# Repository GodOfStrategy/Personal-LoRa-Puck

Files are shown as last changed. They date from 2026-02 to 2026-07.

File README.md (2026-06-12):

# Personal-LoRa-Module
A small compact module made to transmit and receive messages using sub gigahertzs frequencies of radio waves, for use in things such as automation, transmission, reception etc. I wanted to build this for a long time, because I want to implement noise pollution control using these modules, where one module will monitor honking >3 seconds and relay the information of the defaulter's vehicle to the receiver and fine the defaulter.

My LoRa module uses Sub GHz frequencies to tranceive radio waves. It uses the following components:
1. SX1262IMLTRT for transmission and reception.
2. RP2040 for Programing it for various applications.
3. 0900FM15D0039E as an RF filter.
4. AP2112K-3.3 as my LDO.
5. PE4259 as my RF switch.
6. Two quartz timer crystals (12 MHz and 32 MHz).
7. SMD Resistors.
8. SMD Capacitors.
9. SMD Inductors.
10. USB-C Receptacle.

Here is the Schematic:


Here is the PCB:


Here is the assembled PCB:


[Lora-BOM-2.csv](https://github.com/user-attachments/files/28879576/Lora-BOM-2.csv)
Please find the BOM and Firmware along with a 3D STEP file for my assembled PCB in my repo.

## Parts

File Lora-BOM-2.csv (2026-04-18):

Reference | Qty | Value | DNP | Exclude from BOM | Price ($) | Footprint | Datasheet
AE1 | 1 | Antenna |  |  | 4.53 | Connector_PinSocket_2.54mm:PinSocket_1x01_P2.54mm_Vertical | ~
C1,C2 | 2 | 100 nf |  |  | 0.091 | Capacitor_SMD:C_0402_1005Metric | ~
C3 | 1 | 47 nF |  |  | 0.114 | Capacitor_SMD:C_0402_1005Metric | ~
C4,C5 | 2 | 47 pF |  |  | 0.024 | Capacitor_SMD:C_0402_1005Metric | ~
C6 | 1 | 1 nF |  |  | 0.024 | Capacitor_SMD:C_0402_1005Metric | ~
C7,C21 | 2 | 1 uF |  |  | 0.044 | Capacitor_SMD:C_0402_1005Metric | ~
C8,C9,C11,C12,C13,C14,C15,C22,C23 | 9 | 100 nF |  |  | 0.091 | Capacitor_SMD:C_0402_1005Metric | ~
C10,C24 | 1 | 100 nF (C8 - C14 &C24) |  |  | 0.024 | Capacitor_SMD:C_0402_1005Metric | ~
C16,C17 | 2 | 10 uF |  |  | 0.2508 | Capacitor_SMD:C_0402_1005Metric | ~
C18 | 1 | 39 pF |  |  | 0.024 | Capacitor_SMD:C_0402_1005Metric | ~
C19,C20 | 2 | 3.3 pF |  |  | 0.324 | Capacitor_SMD:C_0402_1005Metric | ~
FB1 | 1 | BLM15AX102SN1D |  |  | 0.118 | Inductor_SMD:L_0402_1005Metric | ~
J1 | 1 | USB_C_Receptacle_USB2.0_16P |  |  | 5.088 | Connector_USB:USB_C_Receptacle_G-Switch_GT-USB-7010ASV | https://www.usb.org/sites/default/files/documents/usb_type-c.zip
L1 | 1 | 15uH |  |  | 0.136 | Inductor_SMD:L_0402_1005Metric | ~
L2 | 1 | 47 nH |  |  | 0.1737 | Inductor_SMD:L_0402_1005Metric | ~
L3 | 1 | 9.1 nH |  |  | 0.074 | Inductor_SMD:L_0402_1005Metric | ~
R1 | 1 | 100 |  |  | 0.012 | Resistor_SMD:R_0402_1005Metric | ~
R2,R3 | 2 | 27.4 |  |  | 0.064 | Resistor_SMD:R_0402_1005Metric | ~
R4 | 1 | 10k |  |  | 0.012 | Resistor_SMD:R_0402_1005Metric | ~
R5 | 1 | 1k |  |  | 0.012 | Resistor_SMD:R_0402_1005Metric | ~
R6,R7 | 2 | 5.1 k |  |  | 0.008 | Resistor_SMD:R_0402_1005Metric | ~
SW2 | 1 | BOOTSEL |  |  | 3.39 | Button_Switch_SMD:SW_SPST_PTS647_Sx70 | ~
SW3 | 1 | RESET |  |  |  | Button_Switch_SMD:SW_SPST_PTS647_Sx70 | ~
U1 | 1 | SX1262IMLTRT |  |  | 16.4875 | Package_DFN_QFN:QFN-24-1EP_4x4mm_P0.5mm_EP2.6x2.6mm | https://semtech.file.force.com/sfc/dist/version/download/?oid=00DE0000000JelG&ids=0682R00000IjPWSQA3
U2 | 1 | RP2040 |  |  | 4.827 | Package_DFN_QFN:QFN-56-1EP_7x7mm_P0.4mm_EP3.2x3.2mm | https://datasheets.raspberrypi.com/rp2040/rp2040-datasheet.pdf
U3 | 1 | PE4259 |  |  | 3.0815 | Package_TO_SOT_SMD:SOT-363_SC-70-6 | https://lcsc.com/datasheet/lcsc_datasheet_2409301504_pSemi-PE4259-63_C470892.pdf
U4 | 1 | 0900FM15D0039E |  |  | 9.62` | RF_Converter:Balun_Johanson_0900FM15K0039 | 0900FM15D0039E
U5 | 1 | 12 MHz |  |  | 1.231 | Package_SO:SOIC-8_5.3x5.3mm_P1.27mm | https://www.winbond.com/resource-files/w25q128jv_dtr%20revc%2003272018%20plus.pdf
U6 | 1 | AP2112K-3.3 |  |  | 0.6714 | Package_TO_SOT_SMD:SOT-23-5 | https://www.diodes.com/assets/Datasheets/AP2112.pdf
Y1 | 1 | 32MHz |  |  | 1.405 | Crystal:Crystal_SMD_3225-4Pin_3.2x2.5mm | ~

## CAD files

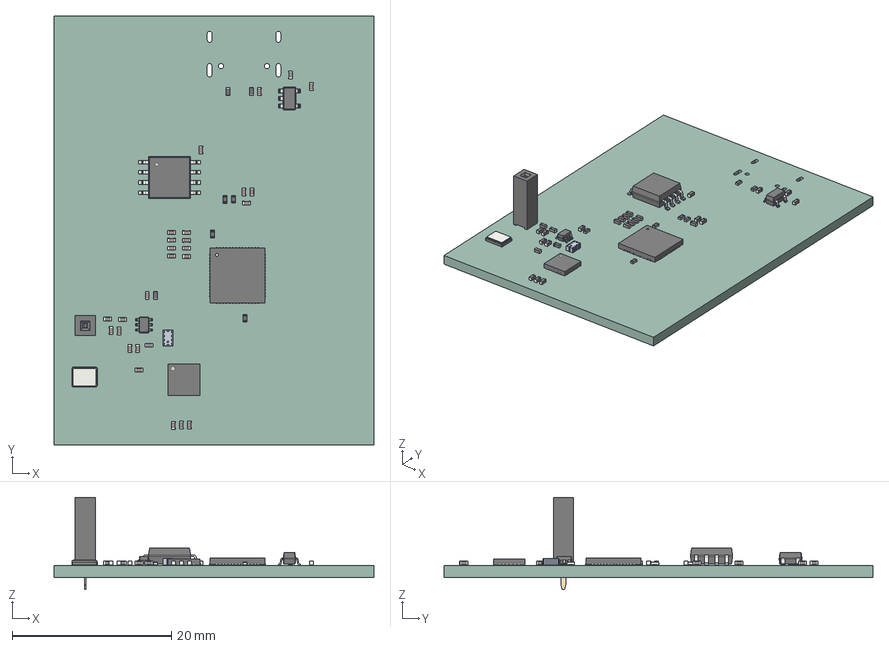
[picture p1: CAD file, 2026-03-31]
lora.step
40.2 x 53.9 x 11.6 mm
C_0402_1005Metric x 23
R_0402_1005Metric x 7
PinSocket_1x01_P2.54mm_Vertical
SOIC-8_5.3x5.3mm_P1.27mm
QFN-24-1EP_4x4mm_P0.5mm_EP2.6x2.6mm
L_0402_1005Metric x 4
SOT-23-5
SOT-363_SC-70-6
QFN-56-1EP_7x7mm_P0.4mm_EP3.2x3.2mm
lora 1.39.1
lora 1.39.2
lora 1.39.3
Crystal_SMD_3225-4Pin_3.2x2.5mm
lora_PCB

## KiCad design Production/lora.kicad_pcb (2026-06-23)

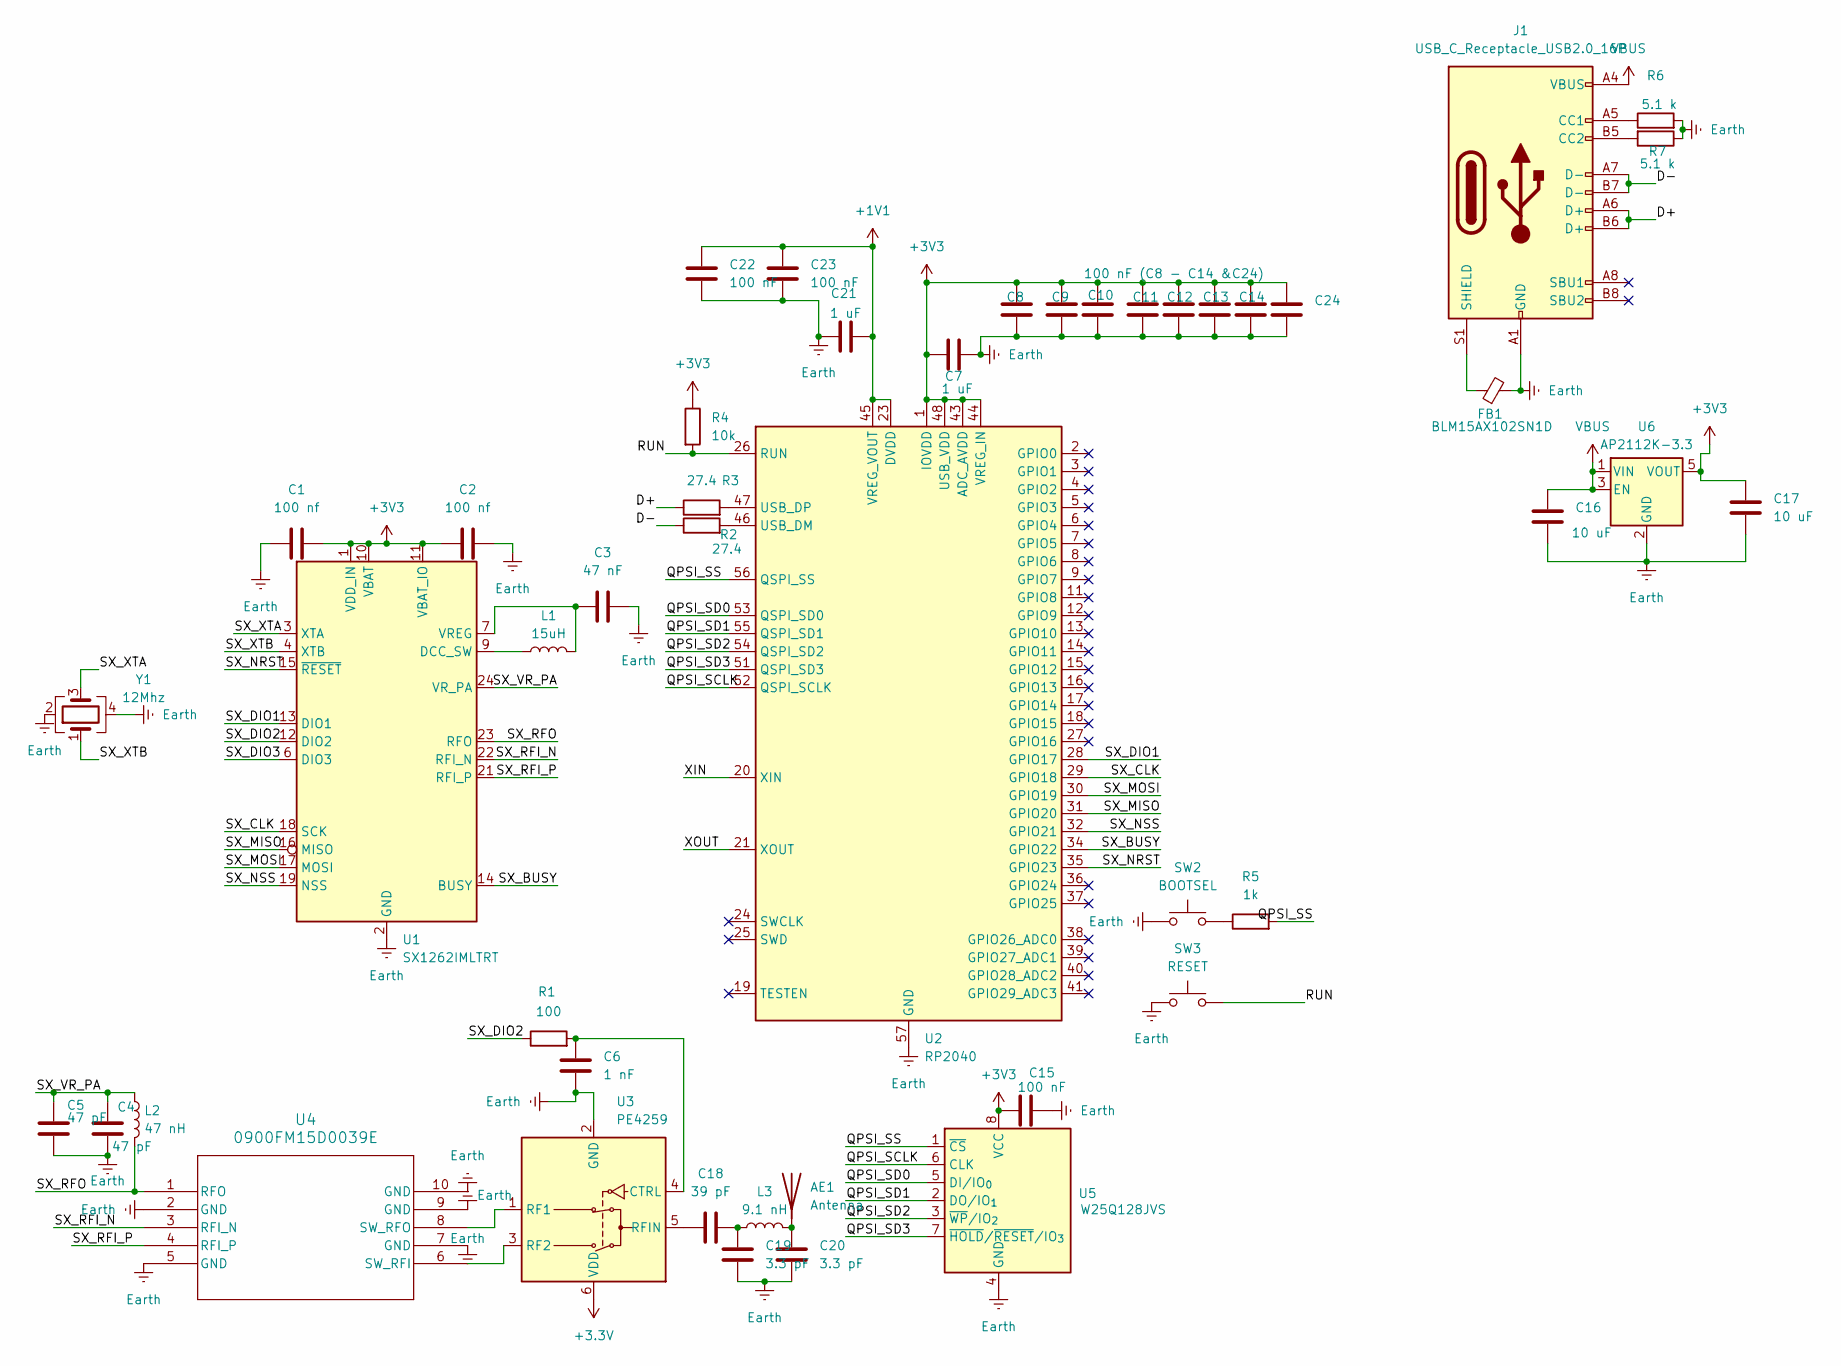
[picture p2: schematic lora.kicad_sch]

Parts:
AE1: Antenna; PinSocket_1x01_P2.54mm_Vertical
C1, C2: 100 nf; C_0402_1005Metric
C3: 47 nF; C_0402_1005Metric
C4, C5: 47 pF; C_0402_1005Metric
C6: 1 nF; C_0402_1005Metric
C7, C21: 1 uF; C_0402_1005Metric
C8, C9, C11, C12, C13, C14, C15, C22, C23: 100 nF; C_0402_1005Metric
C10: 100 nF (C8 - C14 &C24); C_0402_1005Metric
C16, C17: 10 uF; C_0402_1005Metric
C18: 39 pF; C_0402_1005Metric
C19, C20: 3.3 pF; C_0402_1005Metric
C24: 100nF; C_0402_1005Metric
FB1: BLM15AX102SN1D; L_0402_1005Metric
J1: USB_C_Receptacle_USB2.0_16P; USB_C_Receptacle_G-Switch_GT-USB-7010ASV
L1: 15uH; L_0201_0603Metric
L2: 47 nH; L_0402_1005Metric
L3: 9.1 nH; L_0402_1005Metric
R1: 100; R_0402_1005Metric
R2, R3: 27.4; R_0402_1005Metric
R4: 10k; R_0402_1005Metric
R5: 1k; R_0402_1005Metric
R6, R7: 5.1 k; R_0402_1005Metric
SW2: BOOTSEL; SW_SPST_PTS647_Sx70
SW3: RESET; SW_SPST_PTS647_Sx70
U1: SX1262IMLTRT; QFN-24-1EP_4x4mm_P0.5mm_EP2.6x2.6mm
U2: RP2040; QFN-56-1EP_7x7mm_P0.4mm_EP3.2x3.2mm
U3: PE4259; SOT-363_SC-70-6
U4: 0900FM15D0039E; Balun_Johanson_0900FM15K0039
U5: W25Q128JVS; SOIC-8_5.3x5.3mm_P1.27mm
U6: AP2112K-3.3; SOT-23-5
Y1: 12Mhz; Crystal_SMD_3225-4Pin_3.2x2.5mm

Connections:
+1V1: C21.2, C22.1, C23.1, U2.23 (DVDD), U2.45 (VREG_VOUT), U2.50 (DVDD)
+3.3V: U3.6 (VDD)
+3V3: C1.2, C2.1, C7.1, C8.1, C9.1, C10.1, C11.1, C12.1, C13.1, C14.1, C15.1, C17.1, C24.1, R4.1, U1.1 (VDD_IN), U1.10 (VBAT), U1.11 (VBAT_IO), U2.1 (IOVDD), U2.10 (IOVDD), U2.22 (IOVDD), U2.33 (IOVDD), U2.42 (IOVDD), U2.43 (ADC_AVDD), U2.44 (VREG_IN), U2.48 (USB_VDD), U2.49 (IOVDD), U5.8 (VCC), U6.5 (VOUT)
/D+: J1.A6 (D+), J1.B6 (D+), R3.1
/D-: J1.A7 (D-), J1.B7 (D-), R2.1
/QPSI_SCLK: U2.52 (QSPI_SCLK), U5.6 (CLK)
/QPSI_SD0: U2.53 (QSPI_SD0), U5.5 (DI/IO_{0})
/QPSI_SD1: U2.55 (QSPI_SD1), U5.2 (DO/IO_{1})
/QPSI_SD2: U2.54 (QSPI_SD2), U5.3 (~WP/IO_{2})
/QPSI_SD3: U2.51 (QSPI_SD3), U5.7 (~HOLD/~RESET/IO_{3})
/QPSI_SS: R5.2, U2.56 (QSPI_SS), U5.1 (~CS)
/RUN: R4.2, SW3.2, U2.26 (RUN)
/SX_BUSY: U1.14 (BUSY), U2.34 (GPIO22)
/SX_CLK: U1.18 (SCK), U2.29 (GPIO18)
/SX_DIO1: U1.13 (DIO1), U2.28 (GPIO17)
/SX_DIO2: R1.1, U1.12 (DIO2)
/SX_DIO3: U1.6 (DIO3)
/SX_MISO: U1.16 (MISO), U2.31 (GPIO20)
/SX_MOSI: U1.17 (MOSI), U2.30 (GPIO19)
/SX_NRST: U1.15 (~RESET), U2.35 (GPIO23)
/SX_NSS: U1.19 (NSS), U2.32 (GPIO21)
/SX_RFI_N: U1.22 (RFI_N), U4.3 (RFI_N)
/SX_RFI_P: U1.21 (RFI_P), U4.4 (RFI_P)
/SX_RFO: L2.2, U1.23 (RFO), U4.1 (RFO)
/SX_VR_PA: C4.1, C5.1, L2.1, U1.24 (VR_PA)
/SX_XTA: U1.3 (XTA), Y1.3
/SX_XTB: U1.4 (XTB), Y1.1
/XIN: U2.20 (XIN)
/XOUT: U2.21 (XOUT)
Earth: C1.1, C2.2, C3.2, C4.2, C5.2, C6.2, C7.2, C8.2, C9.2, C10.2, C11.2, C12.2, C13.2, C14.2, C15.2, C16.1, C17.2, C19.2, C20.2, C21.1, C22.2, C23.2, C24.2, FB1.2, J1.A1 (GND), J1.A12 (GND), J1.B1 (GND), J1.B12 (GND), R6.2, R7.1, SW2.1, SW3.1, U1.2 (GND), U1.5 (GND), U1.8 (GND), U1.20 (GND), U1.25 (GND), U2.57 (GND), U3.2 (GND), U4.2 (GND), U4.5 (GND), U4.7 (GND), U4.9 (GND), U4.10 (GND), U5.4 (GND), U6.2 (GND), Y1.2, Y1.4
unnamed: AE1.1 (A), C20.1, L3.2
unnamed: C18.2, C19.1, L3.1
unnamed: J1.A5 (CC1), R6.1
unnamed: J1.B5 (CC2), R7.2
unnamed: FB1.1, J1.S1 (SHIELD)
unnamed: R5.1, SW2.2
unnamed: L1.1, U1.9 (DCC_SW)
unnamed: C3.1, L1.2, U1.7 (VREG)
unnamed: R2.2, U2.46 (USB_DM)
unnamed: R3.2, U2.47 (USB_DP)
unnamed: C6.1, R1.2, U3.4 (CTRL)
unnamed: U3.1 (RF1), U4.8 (SW_RFO)
unnamed: U3.3 (RF2), U4.6 (SW_RFI)
unnamed: C18.1, U3.5 (RFIN)
VBUS: C16.2, J1.A4 (VBUS), J1.A9 (VBUS), J1.B4 (VBUS), J1.B9 (VBUS), U6.1 (VIN), U6.3 (EN)

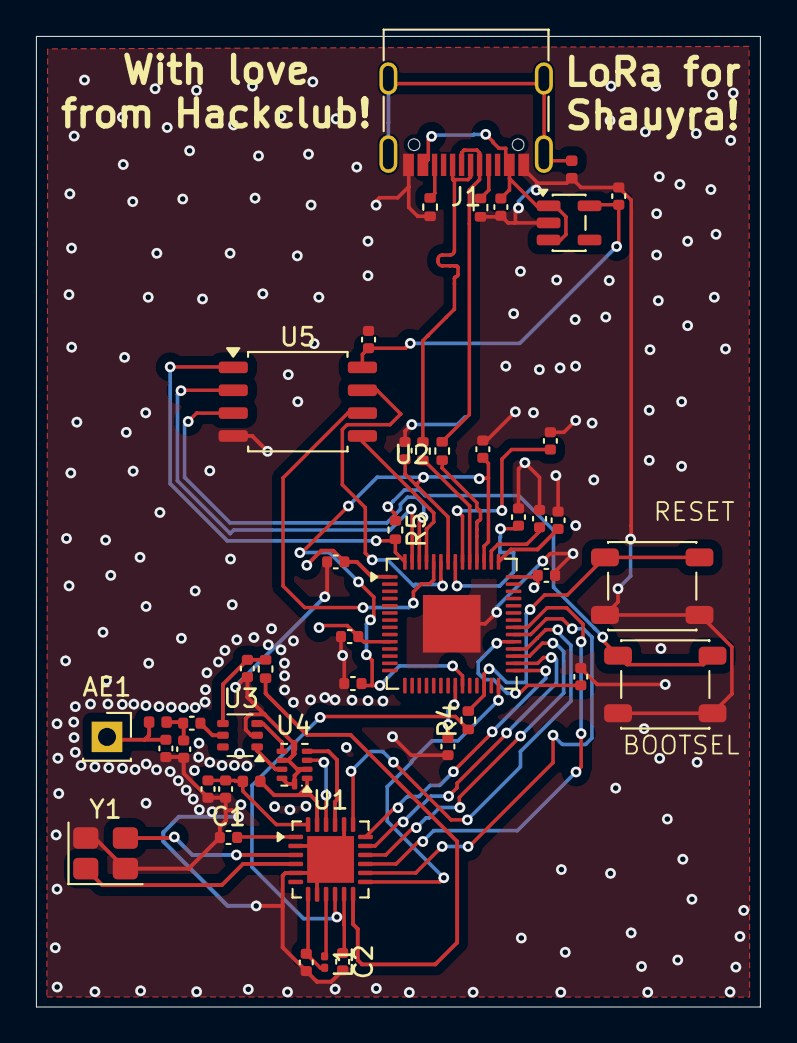
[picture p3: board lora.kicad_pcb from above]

Board: 4 copper layers, 40.2 x 53.9 mm, 46 parts (0 on the bottom side), 41 nets.

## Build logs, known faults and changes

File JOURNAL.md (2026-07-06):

<!--
  This journal is auto generated by Stasis.
-->

# 6/17/2026 1 PM - Working on feedback

_Time spent: 0.4166666666666667h_

Spent some time figuring ot how to troute the USB traces without any vias, and I had an Idea and implemetned it
{F5F5E915-2873-4D16-AF31-E61650D799D2}

I also fixed some unconnected power planes with stitching vias. I also asked on slack how to decide the external capacitor value for the crystal. and I ddint understand what my reviewer meant by routing 1v1 and 3v3 "under" my RP2040, so waiting on reply from him aswell.



# 2/9/2026 4 PM - Completed PCB routing

_Time spent: 5.45h_

Well, it was a vert tedious job to route the PCB. I had to learn new concepts like shielding, routing RF traces, calculating the height of the traces etc. I had to be very careful about routing. Adding the earthing vias made my hand pain like anything! but overall, I believe I did well in the routing.



# 2/8/2026 2 PM - Completed Schematics

_Time spent: 4.25h_

Added all the components following the guided projects pages. Wired them up. For ex: RP 2040, SX 1262, crystals (12 & 32 MHz) USB_C receptacle etc. I just needed to download the "0900FM15D0039E" symbol and footprint form the manufacturer website, and import it into KiCad. Except that everything was easy as pie.  



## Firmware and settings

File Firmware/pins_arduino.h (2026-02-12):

#pragma once

// ===== LED =====
#define PIN_LED         25
#ifndef LED_BUILTIN
#define LED_BUILTIN     PIN_LED
#endif

// ===== UART =====
#define PIN_SERIAL_TX   0     // USB/UART TX
#define PIN_SERIAL_RX   1     // USB/UART RX

// ===== I2C =====
#define PIN_WIRE_SDA    8
#define PIN_WIRE_SCL    9

// ===== SPI (LoRa SX1262) =====
#define PIN_SPI_SCK     2
#define PIN_SPI_MOSI    3
#define PIN_SPI_MISO    4
#define PIN_LORA_NSS    5     // Chip select
#define PIN_LORA_DIO1   6
#define PIN_LORA_BUSY   7
#define PIN_LORA_RESET  22

// ===== RF switch =====
#define PIN_RF_SWITCH   10

// ===== ADC =====
#define PIN_A0          26
#define PIN_A1          27
#define PIN_A2          28

// ===== Debug pins =====
#define PIN_SWCLK       24
#define PIN_SWDIO       25

// ===== Default interfaces =====
#define SERIAL_PORT_MONITOR   Serial
#define SERIAL_PORT_HARDWARE  Serial1
